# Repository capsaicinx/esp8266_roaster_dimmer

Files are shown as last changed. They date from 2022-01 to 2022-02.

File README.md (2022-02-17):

# esp8266_roaster_dimmer
Create an Artisan controlled coffe roaster out of an Klarstein VitAir hot air fryer!
This project combines Yoku-San's initial project for the "BilloJoe" and LeFish's websocket implementation.
* [Project video by Yoku-San](https://www.youtube.com/watch?v=pTog0-5Rx7I)
* [Kaffe-Netz.de project thread](https://www.kaffee-netz.de/threads/umbau-heissluftfritteuse-zu-artisan-gesteuertem-kaffeeroester-billojoe-v2-komplettes-tutorial.133648/)
* [YokuSun initial project dropbox](https://www.dropbox.com/sh/431hbvdjr7k1vzb/AACo8r3lY0x2tSdt06G-mDh7a?dl=0)
* [LeFish project](https://github.com/LeFish1/ESP8266_CoffeeRoaster)
* [Conversion from dimmer Yoku-San's dimmer values](https://www.kaffee-netz.de/threads/umbau-heissluftfritteuse-zu-artisan-gesteuertem-kaffeeroester-billojoe-v2-komplettes-tutorial.133648/page-11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)

## What's inside?
* [scr](/src): Arduino sketch for Adafruit feather ESP8266.
* [lib](/lib): Library of RDBDimmer modified to work with Adafruit feather ESP8266. All other libraries in sketch can be downloaded via Arduino library manager.
* [3d](/3d): STL files for 3d-printable electronics box (split in 5 parts so it can be print faster on multiple printers and glued together afterwards).
* [img](/img): Pictures used in this readme.
* [artisan](/artisan): TBD

## How does it work?
Build based on BilloJoe project video, but with saxe74 & Richards variation of dimmer wiring (see Kaffe-Netz thread).
Adafruit feather ESP8266 used to open websocket connection with Artisan.
ESP8266 reads max6675 thermocouple values and control heating via rbdimmer.

Currently no WifiManager implementation, if Wifi credentials change sketch needs to be modified and re-uploaded.

## How to start?
Change wifi credentials to our own, adjust static IP setting to your environment.

Look at used libraries in sketch and import them to arudino (either via arduino library manager or via github),
library creators are mentioned in sketch so they should be easy to find.
If RBDDimmer does not work for your ESP8266 board, chances are high you need the modified one included in this repo (see sketch comment for more details).

Built for your board and upload to esp. 
Use Artisan configuration provided in this repo (remember to change websocket IP to IP of esp you configured).

## Box for electronics
You can use the files from the [/3d](/3d) folder to print as small box for the electronics.
It was designed to be printed on multiple printer simultanously for faster production time, and then glued together.  
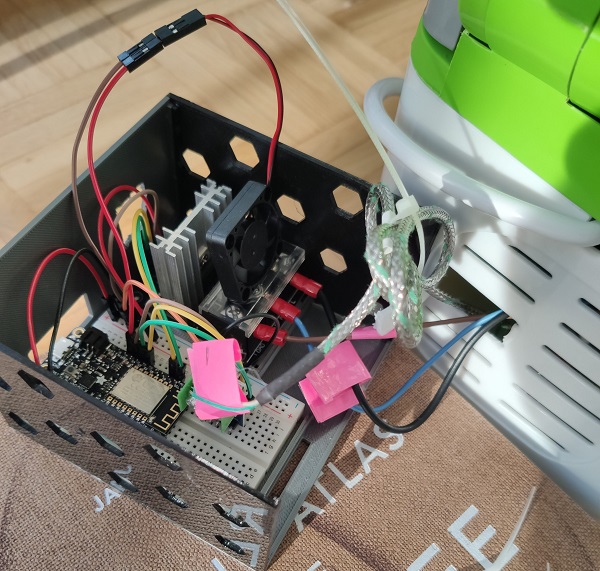
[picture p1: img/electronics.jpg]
Box opened
  
Route the needed cables (AC-IN L, N, Load, and termocouple) out of the back of the roaster like this:  
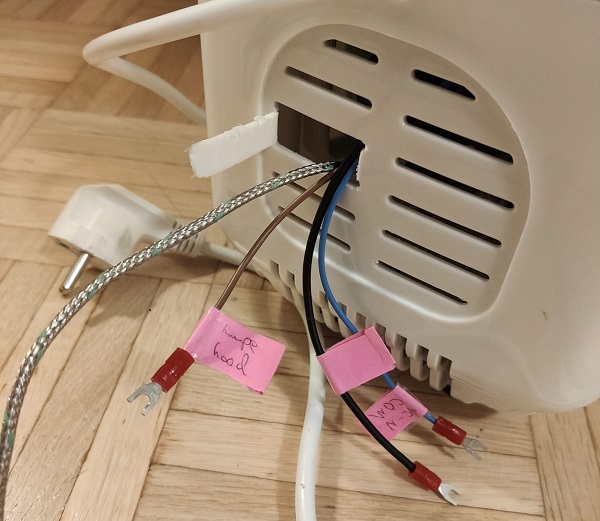
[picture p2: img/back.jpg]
Cable routing
  
You can attach the electronics box with removable zip-ties to the back of the roaster:  
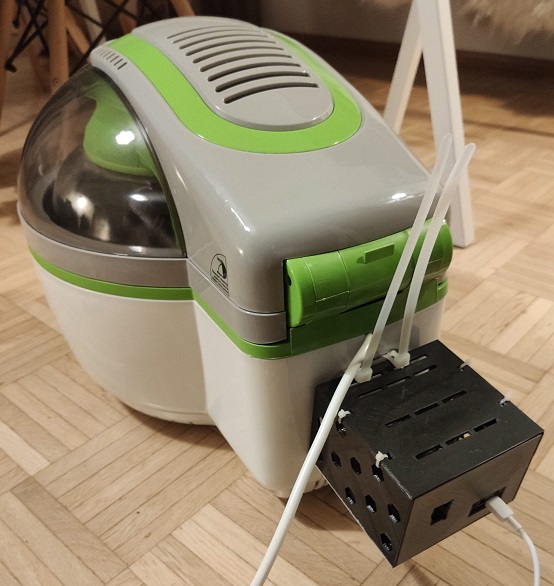
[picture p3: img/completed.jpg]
Finished
  

## Circuit
[ASCIIFLOW](https://asciiflow.com/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)

                                                        +---------------+          +-+
                               5V GND              +3v3-+VCC  MAX6675   |          |+|
                                | |                     |               |          +-+
                                | |           +---------+SCK           ++----------+ |
                                | |           |         |               |            |
                               ++-++          | +-------+CS             |            |
                           +---+USB+---+      | |       |               |            |
                           |  ESP8266  |      | |  +----+SO            -+------------+
                           | Adafruit  |      | |  |    |               |
                           | Feather   |      | |  | +--+GND            |
    +---------+            |        USB+-5V+  | |  | |  +---------------+
    |         |       +3v3-+3V         |      | |  | v
    | 5V   VCC+-5V+        |           |      | |  |
    | FAN     |         +--+GND     D15+------+ |  |
    |      GND+--+      |  |           |        |  |                            
    |         |  |      v  |        D13+--------+  |
    +---------+  v         |           |           |
                           |        D12+-----------+    +-----------------+
                           |           |                |     RBDDimmer   |
                           |         D5+----------------+PWM       AC-IN L+----- Thermofuse/ACL-IN
                           |           |                |                 |
                           |         D2+----------------+ZC               |
                           |           |                |          AC-IN N+----- COM
                           +-----------+           +3v3-+VC               |
                                                        |                 |
                                                     +--+GND              |                   
                                                     |  |           LOAD L+----- Heater
                                                     v  +-----------------+
      _    _                                  
     | |  | |                                 
     | |__| | __ _ _ __  _ __  _   _          
     |  __  |/ _` | '_ \| '_ \| | | |         
     | |  | | (_| | |_) | |_) | |_| |         
     |_|  |_|\__,_| .__/| .__/ \__, |         
                  | |   | |     __/ |         
      _____       |_|   |_| _  |___/          
     |  __ \               | | (_)            
     | |__) |___   __ _ ___| |_ _ _ __   __ _ 
     |  _  // _ \ / _` / __| __| | '_ \ / _` |
     | | \ \ (_) | (_| \__ \ |_| | | | | (_| |
     |_|  \_\___/ \__,_|___/\__|_|_| |_|\__, |
                                         __/ |
                                        |___/

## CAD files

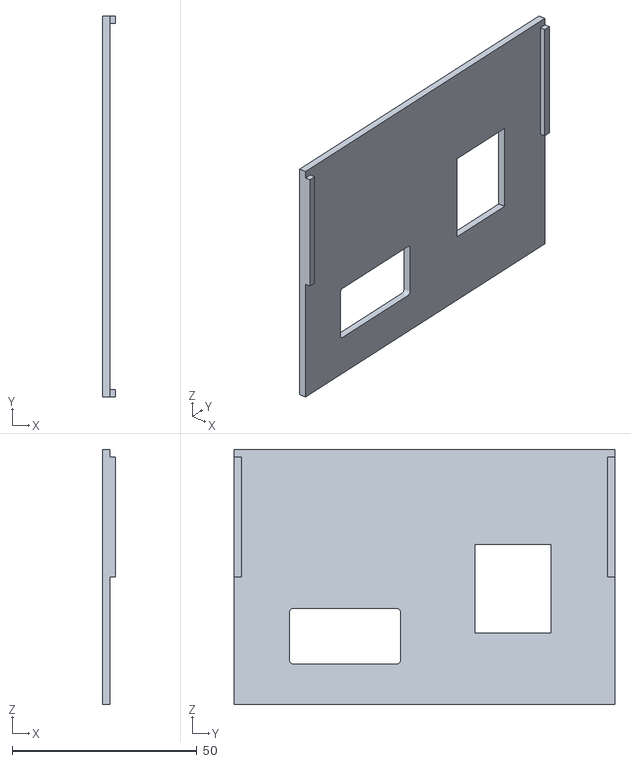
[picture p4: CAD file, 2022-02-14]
3d/Back.stl
3.50 x 103.0 x 69.0

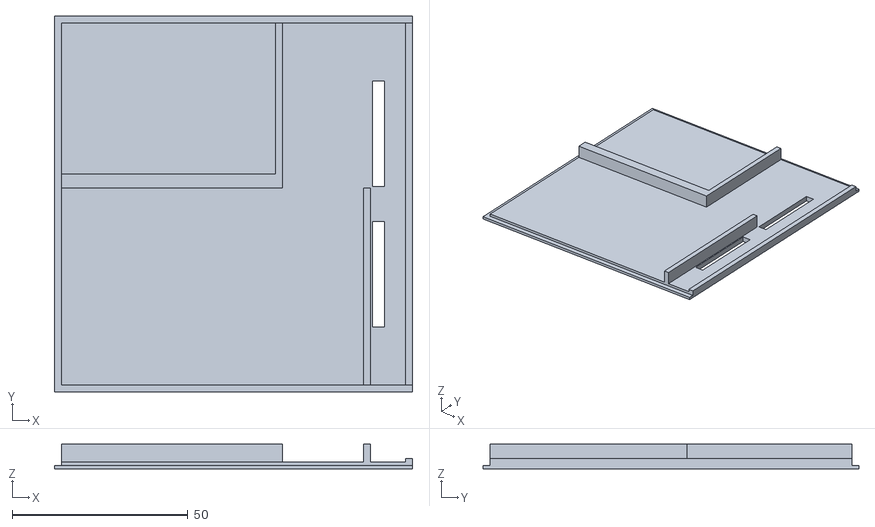
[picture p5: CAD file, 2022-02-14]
3d/Base.stl
102.0 x 107.0 x 7.00

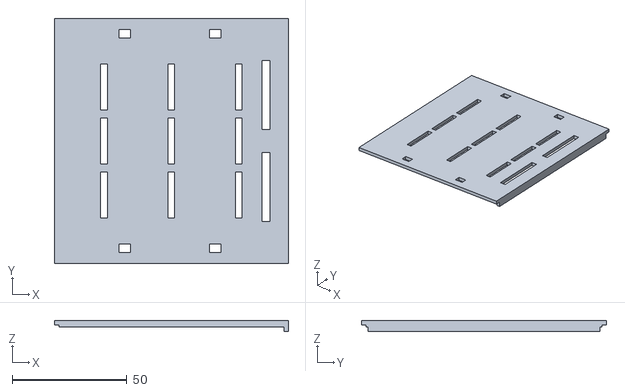
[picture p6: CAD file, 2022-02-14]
3d/Top.stl
102.0 x 107.0 x 5.00

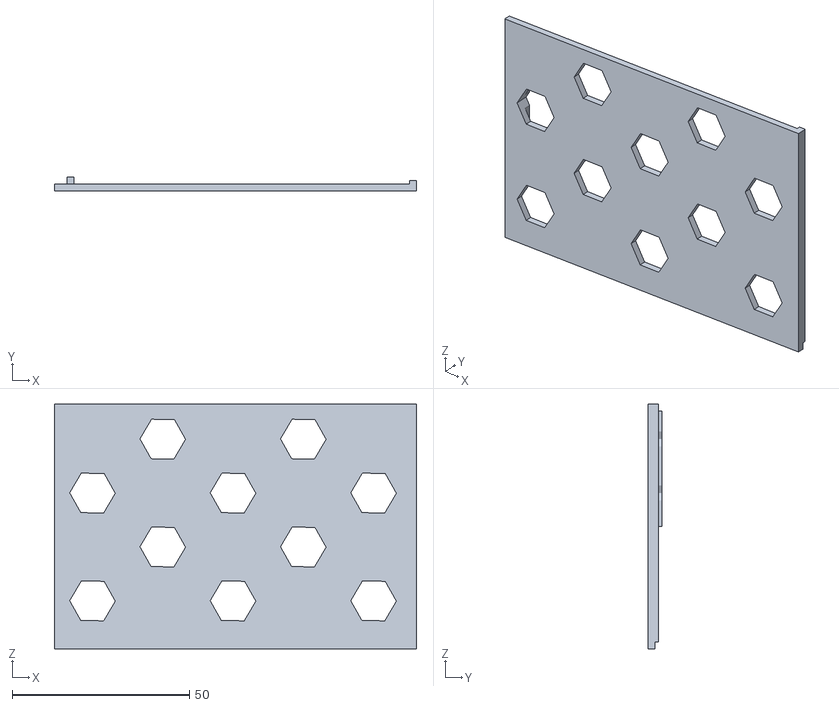
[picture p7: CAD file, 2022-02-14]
3d/SideLeft.stl
102.0 x 4.00 x 69.0

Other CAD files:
3d/SideRight.stl

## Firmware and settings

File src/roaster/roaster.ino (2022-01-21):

/*
 * Sketch by tjburrows as fork of YokuSan and LeFish from kaffee-netz.de
 * Project thread: https://www.youtube.com/watch?v=pTog0-5Rx7I
 * YokuSun initial project dropbox: https://www.dropbox.com/sh/431hbvdjr7k1vzb/AACo8r3lY0x2tSdt06G-mDh7a?dl=0
 * LeFish project: https://github.com/LeFish1/ESP8266_CoffeeRoaster 
 * 
 * 
*  _    _                           _____                 _   _             
*| |  | |                         |  __ \               | | (_)            
*| |__| | __ _ _ __  _ __  _   _  | |__) |___   __ _ ___| |_ _ _ __   __ _ 
*|  __  |/ _` | '_ \| '_ \| | | | |  _  // _ \ / _` / __| __| | '_ \ / _` |
*| |  | | (_| | |_) | |_) | |_| | | | \ \ (_) | (_| \__ \ |_| | | | | (_| |
*|_|  |_|\__,_| .__/| .__/ \__, | |_|  \_\___/ \__,_|___/\__|_|_| |_|\__, |
*             | |   | |     __/ |                                     __/ |
*            |_|   |_|    |___/                                     |___/ 
* 
*/

#include <Arduino.h>
#include <FS.h>

/*Dimmer Config 
 * ATTENTION: be aware this lib needs to be modified inorder to work with ESP8266
 * Either use the one provided in github or refer to https://github.com/RobotDynOfficial/RBDDimmer/issues/14
 */
#include <RBDdimmer.h>
const int outputPin = 5;
const int zerocross = 2; // for boards with CHANGEBLE input pins
dimmerLamp dimmer(outputPin, zerocross); //initialase port for dimmer for ESP8266, ESP32, Arduino due boards


//Wifi libs 
#include <ESP8266WiFi.h>
#include <WebSocketsServer.h> //Websockets Lib by links2004

//Thermocouple
#include <MAX6675_Thermocouple.h> //Lib by YuriiSaliov
#include <RunningMedian.h> //Lib by RobTillaart

//JSON for Artisan Websocket implementation
#include "ArduinoJson.h"

//Ticker to execute actions at defined intervals
#include "TickTwo.h" //ESP8266 compatible version of Ticker by sstaub
 
WebSocketsServer webSocket = WebSocketsServer(8080);

//Wifi Config 
const char *ssid     = "YOURSSID";
const char *password = "YOURPW";

// Set your Static IP address
IPAddress local_IP(192, 168, 0, 47);
// Set your Gateway IP address
IPAddress gateway(192, 168, 0, 1);
IPAddress subnet(255, 255, 255, 0);

//Initialize needed variables
int DimmerVal = 0;
float BeanTemp = 21.0;
float randomnumber = 0;
 
#define DEBUG_SERIAL Serial

/*
 * Smoothed bean temperature measurement using MAX6675_Thermocouple by Yurii Salimov
 * https://github.com/YuriiSalimov/MAX6675_Thermocouple
 * implementation by LeFish
 */
int SCK_PIN = 15;
int BeanTemp_CS_PIN = 13;
int SO_PIN = 12;
 
Thermocouple* originThermocouple = NULL;
RunningMedian Med_BeanTemp = RunningMedian(6);
void measureBeanTemp()
{
  //BeanTemp = SmoothBeanTemp->readCelsius();
  float this_BeanTemp = originThermocouple->readCelsius();
  Med_BeanTemp.add(this_BeanTemp);
}


//Define Artisan Websocket events to exchange data
void webSocketEvent(uint8_t num, WStype_t type, uint8_t * payload, size_t length) {

  //Artisan schickt Anfrage als TXT
  //TXT zu JSON lt. https://forum.arduino.cc/t/assistance-parsing-and-reading-json-array-payload-websockets-solved/667917

  const size_t capacity = JSON_OBJECT_SIZE(3) + 60; //Memory pool
  DynamicJsonDocument doc(capacity);

    switch(type) {
        case WStype_DISCONNECTED:
            Serial.printf("[%u] Disconnected!\n", num);
            break;
        case WStype_CONNECTED:
            {
                IPAddress ip = webSocket.remoteIP(num);
                Serial.printf("[%u] Connected from %d.%d.%d.%d url: %s\n", num, ip[0], ip[1], ip[2], ip[3], payload);
        
                // send message to client
                webSocket.sendTXT(num, "Connected");
            }
            break;
        case WStype_TEXT:
            { 
            //DEBUG WEBSOCKET
            //Serial.printf("[%u] get Text: %s\n", num, payload);

            //Extract Values lt. https://arduinojson.org/v6/example/http-client/
            //Artisan Anleitung: https://artisan-scope.org/devices/websockets/

            deserializeJson(doc, (char *)payload);

            //2 Nodes einzeln (Feld: "command"): "getBT" und "getDimmerVal"
            //oder
            // alle Nodes auf einmal (Feld: "command"): "getData"
            //char* entspricht String
            String command = doc["command"].as<char*>();
            
            Serial.printf("Command received: %s \n",command);  
            
            long ln_id = doc["id"].as<long>();
            //Get BurnerVal from Artisan over Websocket
            if(!doc["BurnerVal"].isNull())
            {
              //Serial.print("BurnerVal: ");
              //Serial.println(doc["BurnerVal"].as<long>());  
              DimmerVal = doc["BurnerVal"].as<long>();
              dimmer.setPower((int)DimmerVal);
              Serial.printf("Dimmer power set to: %u \n",(int)DimmerVal);
            }

            //Send Values to Artisan over Websocket
            JsonObject root = doc.to<JsonObject>();
            JsonObject data = root.createNestedObject("data");
            if(command == "getBT")
            {
              root["id"] = ln_id;
              data["BT"] = Med_BeanTemp.getMedian();
              //randomnumber = rand()%200;
              //data["BT"] = randomnumber;
              //DEBUG_SERIAL.printf("getBT created BT: %f \n", randomnumber);
              DEBUG_SERIAL.printf("getBT reads BT: %f \n", Med_BeanTemp.getMedian());
            }
            else if(command == "getDimmerVal")
            {
              root["id"] = ln_id;
              data["DimmerVal"] = float(DimmerVal);
              Serial.printf("getDIMMERVAL current DV: %f \n", float(DimmerVal));
            }
            else if(command == "getData")
            {
              root["id"] = ln_id;
              data["BT"] = Med_BeanTemp.getMedian();
              //randomnumber = rand()%200;
              //data["BT"] = randomnumber;
              data["DimmerVal"] = float(DimmerVal);
              Serial.printf("getData created BT: %f and current DimmerVal: %f \n", Med_BeanTemp.getMedian(), float(DimmerVal));
            }

            char buffer[200]; // create temp buffer
            size_t len = serializeJson(doc, buffer);  // serialize to buffer

            //DEBUG WEBSOCKET
            //Serial.println(buffer);

            webSocket.sendTXT(num, buffer);

            // send message to client
            // webSocket.sendTXT(num, "message here");

            // send data to all connected clients
            // webSocket.broadcastTXT("message here");
            }
            break;
        case WStype_BIN:
            Serial.printf("[%u] get binary length: %u\n", num, length);
            hexdump(payload, length);

            // send message to client
            // webSocket.sendBIN(num, payload, length);
            break;
    }
}

/*
 *Ticker implementations  
 *Measure Bean Temperature every 250ms
 */
 
void func250MS() {
    measureBeanTemp();
  }
  
TickTwo ticker250MS(func250MS, 250, 0, MILLIS);
 
void setup() {
    DEBUG_SERIAL.begin(115200);
 
//  DEBUG_SERIAL.setDebugOutput(true);
 
    DEBUG_SERIAL.println();
    DEBUG_SERIAL.println();
    DEBUG_SERIAL.println();
 
    for(uint8_t t = 4; t > 0; t--) {
        DEBUG_SERIAL.printf("[SETUP] BOOT WAIT %d...\n", t);
        DEBUG_SERIAL.flush();
        delay(1000);
    }

    //Thermocouple
    originThermocouple = new MAX6675_Thermocouple(SCK_PIN, BeanTemp_CS_PIN, SO_PIN);

    //Start Tickers
    ticker250MS.start();

    //Initialise dimmer
    dimmer.begin(NORMAL_MODE, ON);  
  
    // Configures static IP address
    if (!WiFi.config(local_IP, gateway, subnet)) {
        Serial.println("STA Failed to configure");
    } else {
        Serial.println("STA configured");
      }
    WiFi.begin(ssid, password);
 
    while ( WiFi.status() != WL_CONNECTED ) {
      delay ( 500 );
      Serial.print ( "." );
    }
    DEBUG_SERIAL.print("Local IP: "); DEBUG_SERIAL.println(WiFi.localIP());
    // server address, port and URL
    webSocket.begin();
 
    // event handler
    webSocket.onEvent(webSocketEvent);
}
 
unsigned long lastUpdate = millis();
 
 
void loop() {
    webSocket.loop();
    ticker250MS.update();
}

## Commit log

2022-01-22 Update README.md
    changed circuit diagram (correct dimmer wiring and 5v fan using usb instead of bat port)
2022-01-22 Update README.md
    added kaffe netz thread to readme
2022-01-22 Update README.md
    mentioned saxe74 as creator of dimmer wiring
2022-02-14 Added 3d files of printable electronics box
    [Back.stl, Base.stl, SideLeft.stl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]
2022-02-14 Update README.md
    updated schematics
2022-02-17 Added working Artisan config derived/converted from Yoku-Sans current one
